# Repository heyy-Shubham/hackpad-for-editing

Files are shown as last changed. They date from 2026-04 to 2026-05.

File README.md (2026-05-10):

h## Hackpad For Editing

## Why I Built This

As a video editor, I was tired of reaching across the keyboard
for shortcuts like Undo, Redo, and Zoom constantly.
I wanted a dedicated device that keeps my hands in the editing
zone — so I built the Hackpad For Editing.

I will make this device using 9 sw_cherry_mx (switch) and encoder and 0.91 oled display
just plug and enhance editing leval build for editors

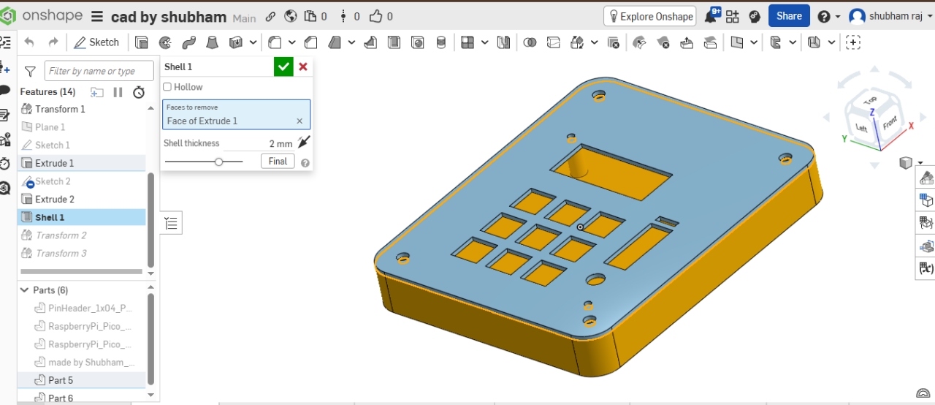
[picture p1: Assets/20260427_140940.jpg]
Hackpad


## What does this do
9 sw_cherry_mx mechanichl switch , Every switch maped editing shortcut 
rotary encoder for layer moveing left And right
Using Like a Standerd Usb Keyboard
Firamware using PlatformIO + keyboard.h in raspbarry pi pico micro controllar

## keyboard shortcuts
| key | Shortcut | Funcation |
|---|---|---|
| SW1 | Tab | Switch between panel |
| SW2 | Win + Swift + S | Screemshot |
| SW3 | Ctrl z | undo |
| SW4 | Ctrl + Swift + z | Redo |
| SW5 | End | Jumpto the end time line |
| SW6 | Alt + 2 | Application specific Shortcut |
| SW7 | Ctrl + B | Split Clip |
| SW8 | Ctrl + = | Zoom in |
| SW9 | Ctrl + - | Zoom Out |
| Encoder Clockwise | Rise Arrow | Time line forward |
| Encoder Anti-Clockwise | Left Arrow | Backward |

## Connectioms Of Respberry To switches
| Component | Pin | 
|---|---|
| SW1 | D2 |
| SW2 | D3 |
| SW3 | D4 |
| SW4 | D5 |
| SW5 | D6 |
| SW6 | D7 |
| SW7 | D8 |
| SW8 | D9 |
| SW9 | D10 |
| Encoder  A | D20 |
| Encoder  B | D21 |

# Component 
1. Switch (sw_cherry_mx)
2. Custom Design PCB
3. Encoder
4. 0.91inch OLED Display
5. Enclosure 

## Firamware Flash in Respberry pi pico
 1. install vs code (https://code.visualstudio.com/)
 2. Add Extension PlatformIO Extension
 3. Select Board And install Firamware

# Fallout Zine Page
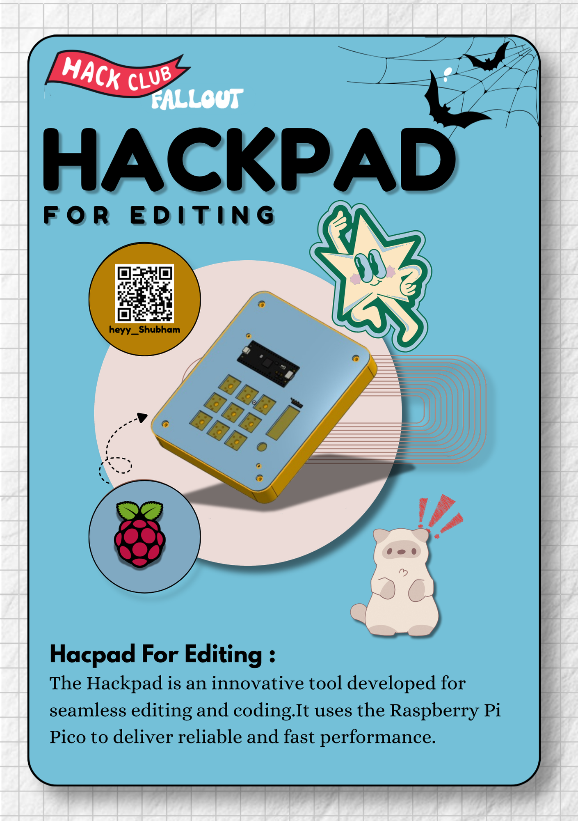
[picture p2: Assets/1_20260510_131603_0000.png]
Poster


## PCB
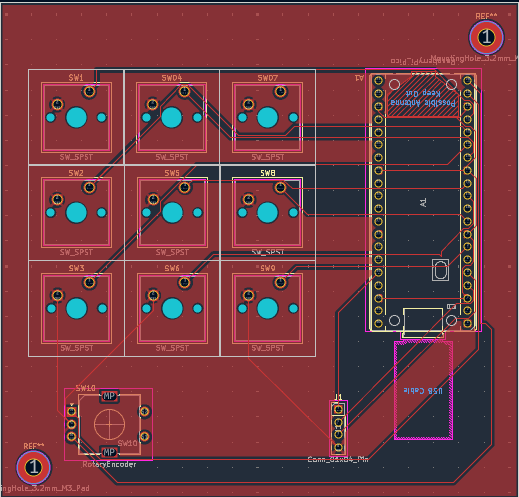
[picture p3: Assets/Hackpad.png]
PCB


# Cad Source File 
OneShap Project Link:
https://cad.onshape.com/documents/5b5dae307a075cbb770b9d40/w/47bce3600617231dbb59e220/e/9a00e2926e7c151da0a35bf5

## CAD
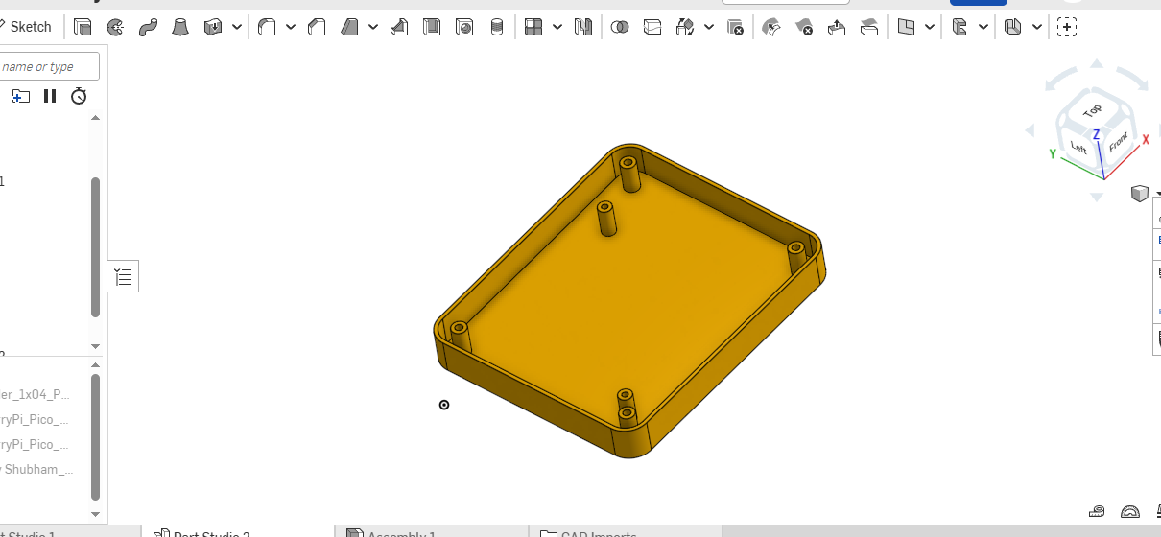
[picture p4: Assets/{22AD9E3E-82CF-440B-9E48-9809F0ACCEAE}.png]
Case


##Author
Shubham Raj - @heyy-Shubham(https://github.com/heyy-shubham)

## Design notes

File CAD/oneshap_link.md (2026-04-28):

# Cad Source File 
OneShap Project Link:
https://cad.onshape.com/documents/5b5dae307a075cbb770b9d40/w/47bce3600617231dbb59e220/e/9a00e2926e7c151da0a35bf5

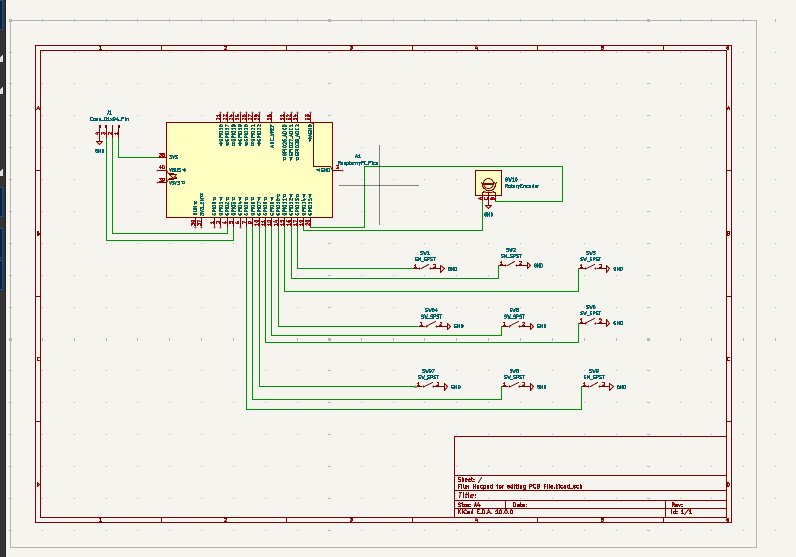
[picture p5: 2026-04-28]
Assets/Screenshot 2026-04-28 001617.png

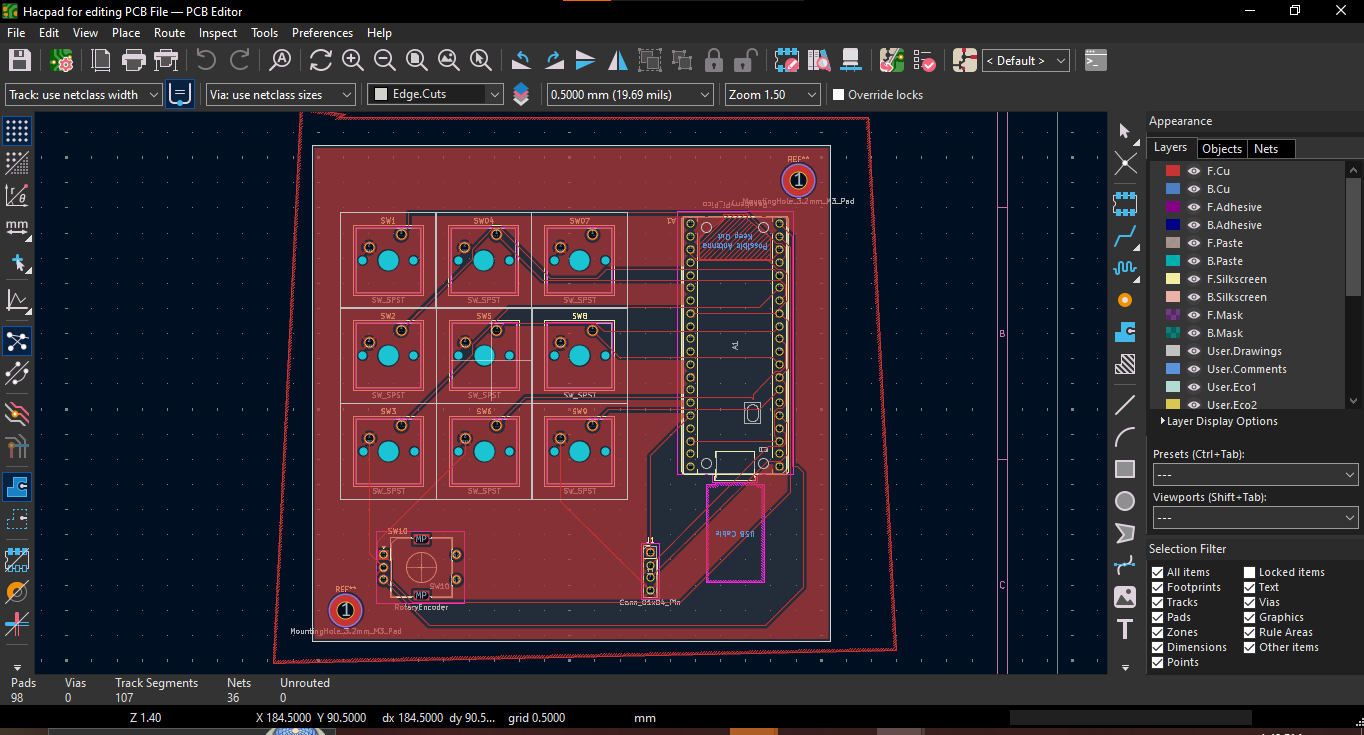
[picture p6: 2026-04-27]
Assets/pcb.jpg

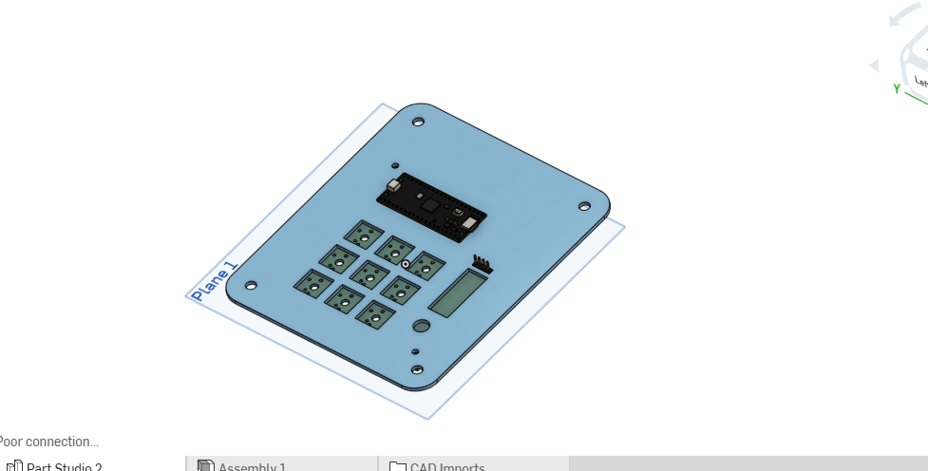
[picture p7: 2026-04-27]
Assets/{4853B936-79CA-4EE4-9DD8-A8C7A89B42EC}.png

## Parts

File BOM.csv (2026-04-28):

Name | Quantity | Price (USD) | Link
Raspberry Pi Pico | 1 | 4.80 | https://robocraze.com/products/raspberry-pi-pico
Cherry MX Switches | 9 | 3.80 | https://meckeys.com/shop/accessories/keyboard-accessories/key-switches/cherry-mx2a-switch/
Rotary Encoder EC11 | 1 | 1.20 | https://amzn.in/d/09X5ElfV
0.91 inch OLED SSD1306 | 1 | 2.60 | https://www.amazon.in/dp/B099X21CM5
3D Printed Case PLA | 1 | 3.00 | https://www.amazon.in
USB Micro Cable | 1 | 1.50 | https://www.amazon.in
PCB Manufacturing JLCPCB | 1 | 5.00 | https://jlcpcb.com

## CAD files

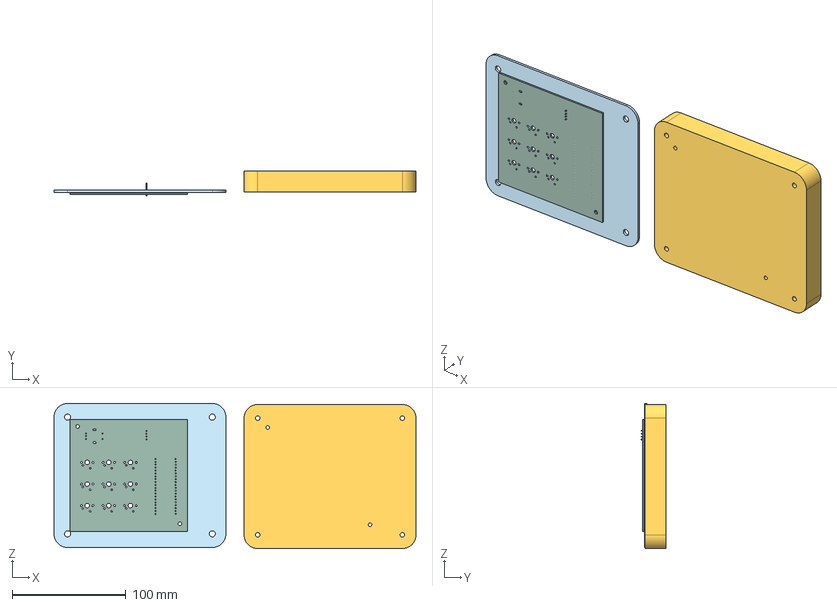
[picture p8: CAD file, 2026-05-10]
CAD/Assembly 1.step
318.3 x 22.2 x 127.5 mm
made by Shubham_PCB
PinHeader_1x04_P2.54mm_Vertical

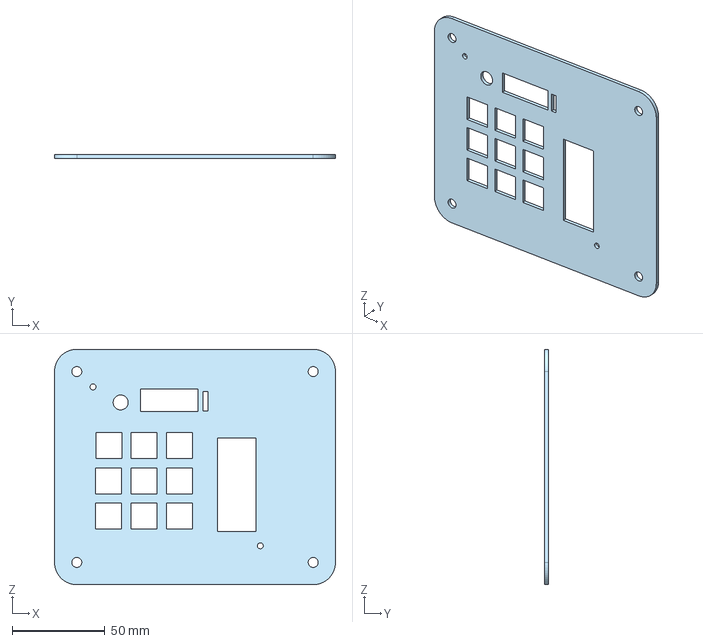
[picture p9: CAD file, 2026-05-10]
CAD/Part Studio 2 - Part 6.step
151.2 x 2.00 x 126.6 mm

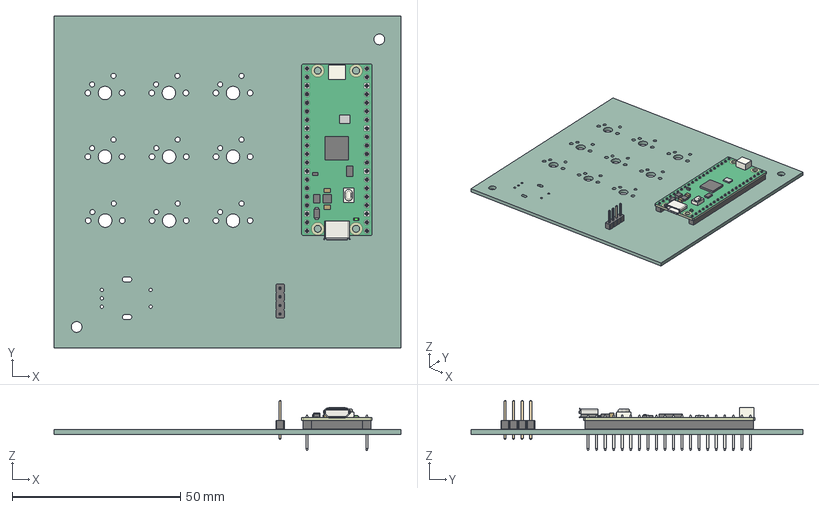
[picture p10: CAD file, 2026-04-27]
PCB/.step
103.2 x 98.6 x 14.9 mm
PinHeader_1x04_P2.54mm_Vertical
RaspberryPi_Pico_H_Module_KiCad
RaspberryPi_Pico_Header_DIP-40_H2.54mm_KiCad
made by Shubham_PCB

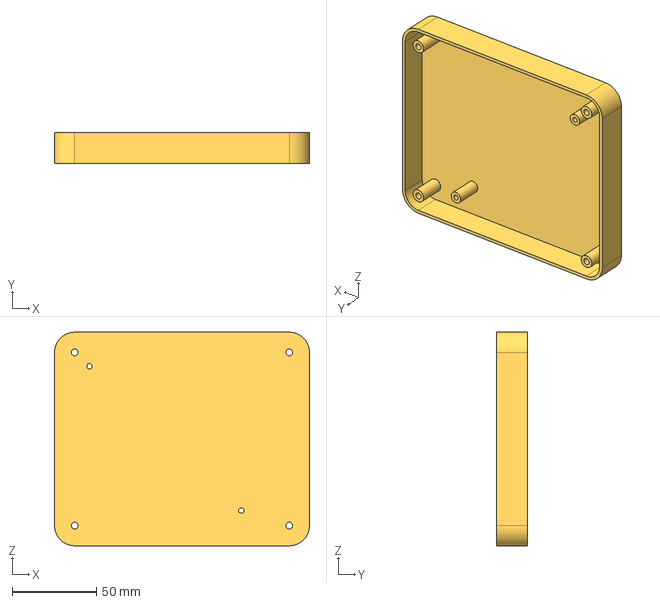
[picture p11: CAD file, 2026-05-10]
CAD/Part Studio 2 - Part 5 (1).step
151.2 x 18.5 x 126.6 mm

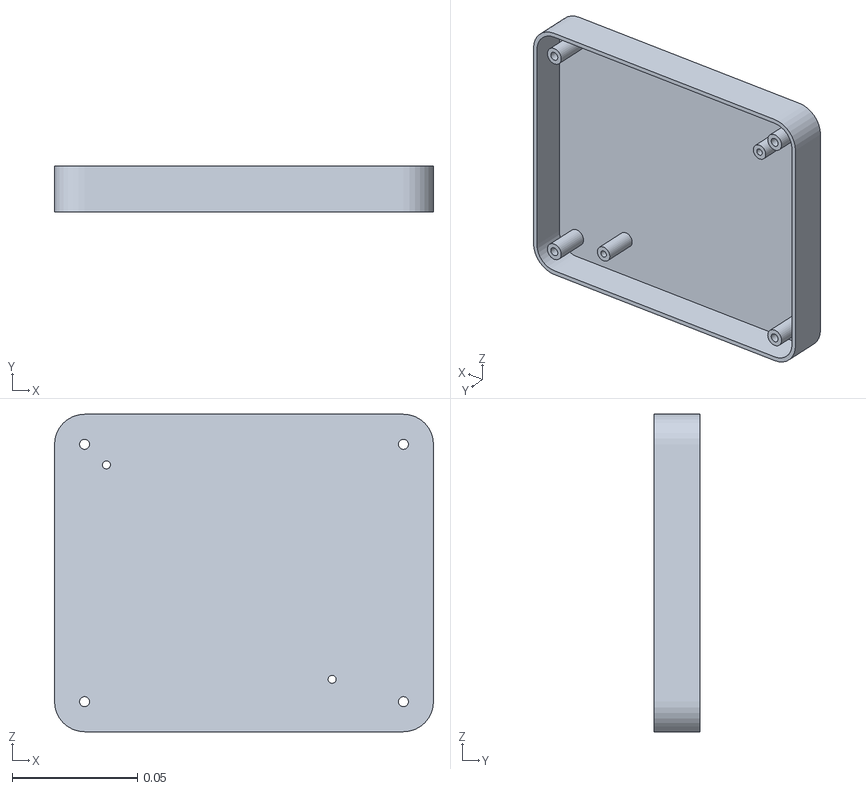
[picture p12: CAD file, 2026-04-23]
CAD/Body.stl
0.151 x 0.0185 x 0.127

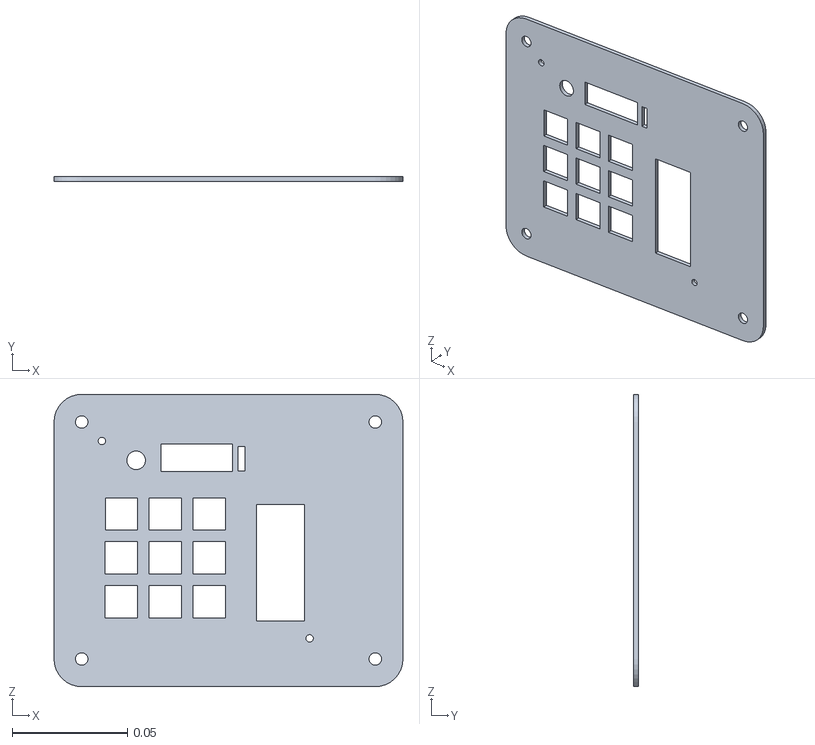
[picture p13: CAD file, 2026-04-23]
CAD/Top.stl
0.151 x 0.002 x 0.127

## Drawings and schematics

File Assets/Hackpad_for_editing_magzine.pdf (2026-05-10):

## HACKPAD F O R E D I T I N G

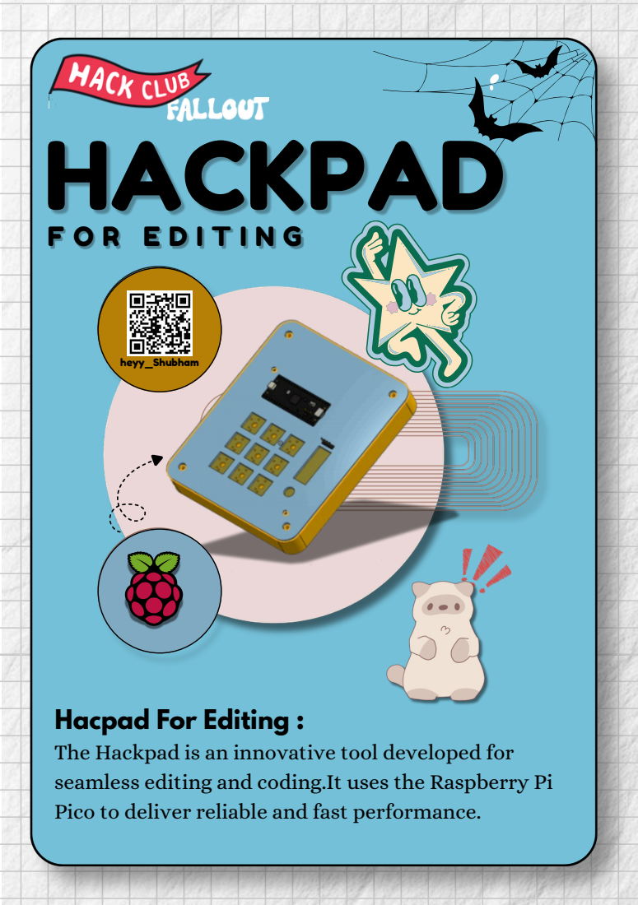
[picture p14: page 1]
heyy_Shubham

Hacpad For Editing :
The Hackpad is an innovative tool developed for
seamless editing and coding.It uses the Raspberry Pi
Pico to deliver reliable and fast performance.

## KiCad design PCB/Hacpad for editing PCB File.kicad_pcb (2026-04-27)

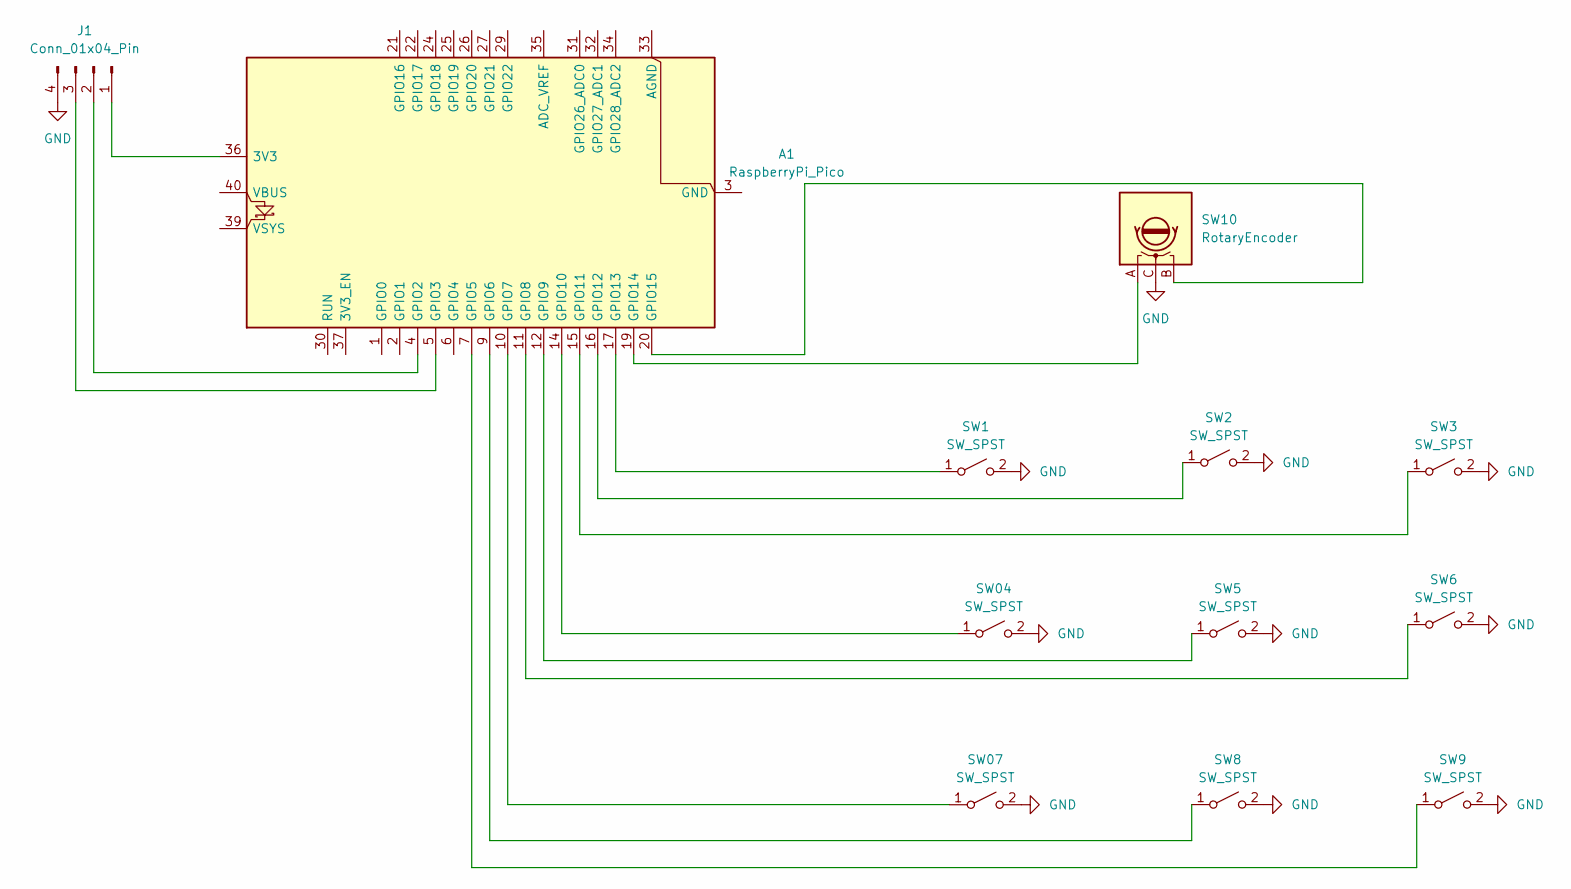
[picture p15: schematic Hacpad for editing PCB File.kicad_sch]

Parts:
A1: RaspberryPi_Pico; RaspberryPi_Pico_Common_Unspecified
J1: Conn_01x04_Pin; PinHeader_1x04_P2.54mm_Vertical
SW1, SW2, SW3, SW04, SW5, SW6, SW07, SW8, SW9: SW_SPST; SW_Cherry_MX_1.00u_PCB
SW10: RotaryEncoder; RotaryEncoder_Alps_EC11E-Switch_Vertical_H20mm

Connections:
GND: J1.4, SW1.2 (B), SW2.2 (B), SW3.2 (B), SW04.2 (B), SW5.2 (B), SW6.2 (B), SW07.2 (B_2), SW8.2 (B), SW9.2 (B), SW10.C
unnamed: A1.36 (3V3), J1.1
unnamed: A1.3 (GND), A1.8 (GND), A1.13 (GND), A1.18 (GND), A1.23 (GND), A1.28 (GND), A1.38 (GND)
unnamed: A1.4 (GPIO2), J1.2
unnamed: A1.5 (GPIO3), J1.3
unnamed: A1.7 (GPIO5), SW9.1 (A)
unnamed: A1.9 (GPIO6), SW8.1 (A)
unnamed: A1.11 (GPIO8), SW6.1 (A)
unnamed: A1.12 (GPIO9), SW5.1 (A)
unnamed: A1.14 (GPIO10), SW04.1 (A)
unnamed: A1.15 (GPIO11), SW3.1 (A)
unnamed: A1.16 (GPIO12), SW2.1 (A)
unnamed: A1.17 (GPIO13), SW1.1 (A)
unnamed: A1.19 (GPIO14), SW10.A
unnamed: A1.20 (GPIO15), SW10.B

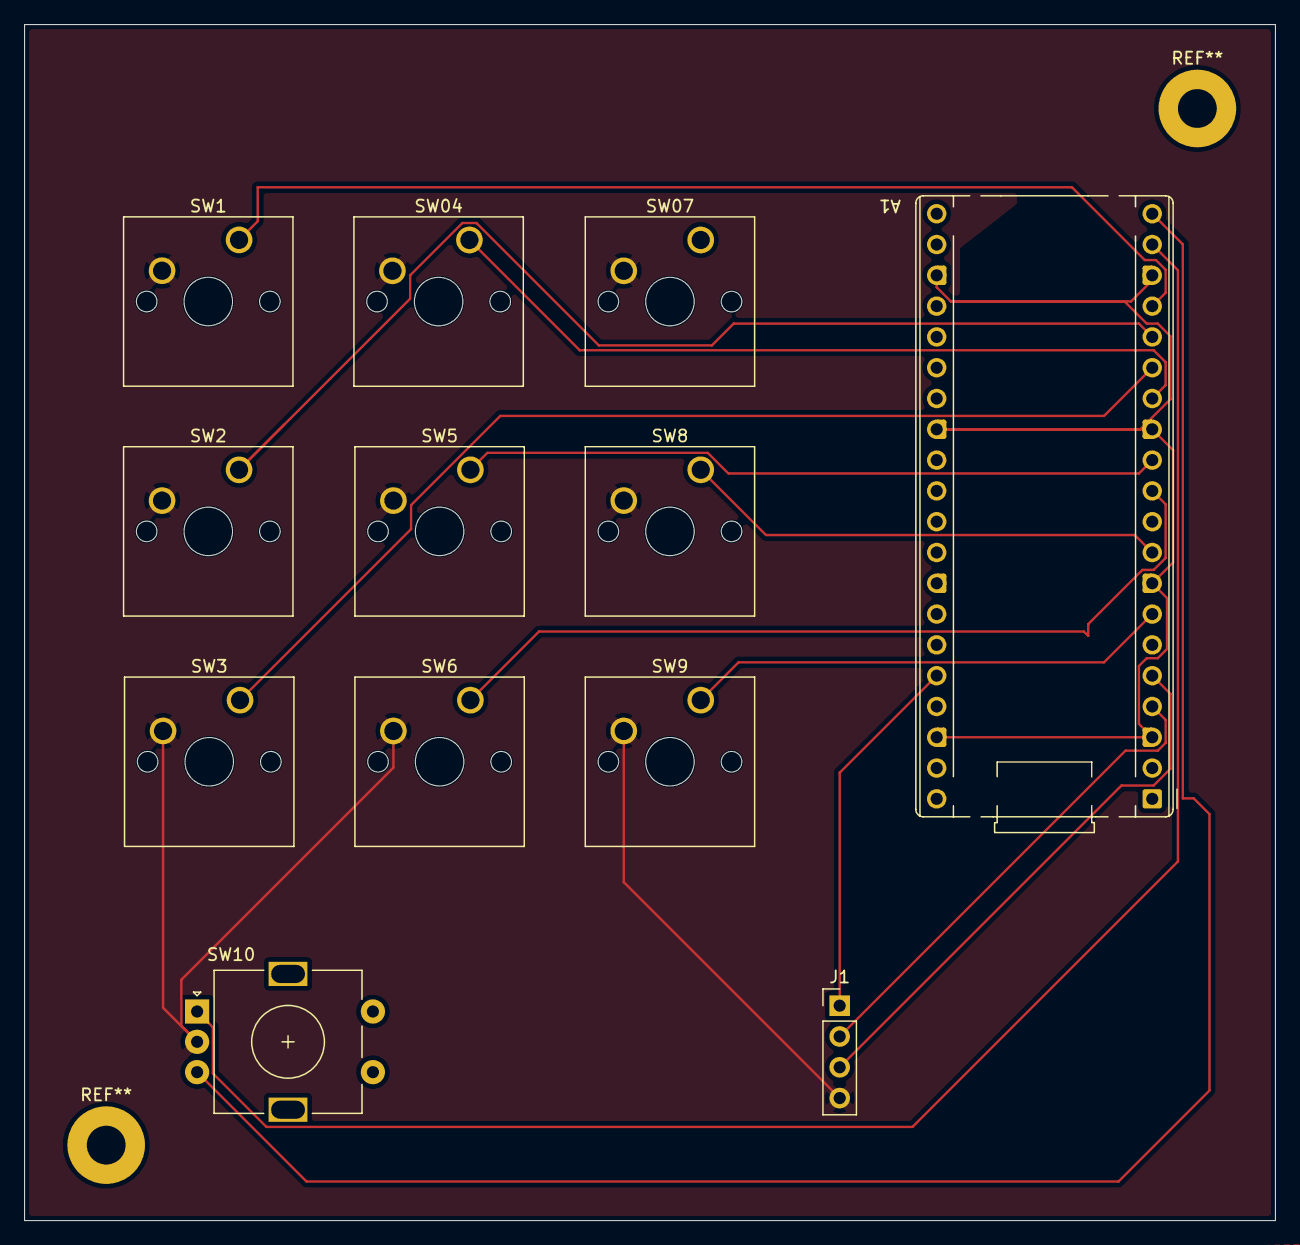
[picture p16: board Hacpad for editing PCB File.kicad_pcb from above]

Board: 2 copper layers, 103.2 x 98.6 mm, 12 parts (0 on the bottom side), 15 nets.

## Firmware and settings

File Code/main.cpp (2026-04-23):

#include <Arduino.h>
#include <Keyboard.h>

#define SW1  2
#define SW2  3
#define SW3  4
#define SW4  5
#define SW5  6
#define SW6  7
#define SW7  8
#define SW8  9
#define SW9  10
#define ENC_A 20
#define ENC_B 21

bool lastA = HIGH;
const int buttons[] = {SW1,SW2,SW3,SW4,SW5,SW6,SW7,SW8,SW9};
const int NUM_BUTTONS = 9;
bool lastState[9];
unsigned long lastPress[9];
#define DEBOUNCE 50

void pressKey(int sw) {
  switch (sw) {
    case 0: Keyboard.press(KEY_TAB); Keyboard.releaseAll(); break;
    case 1: Keyboard.press(KEY_LEFT_GUI); Keyboard.press(KEY_LEFT_SHIFT); Keyboard.press('s'); Keyboard.releaseAll(); break;
    case 2: Keyboard.press(KEY_LEFT_CTRL); Keyboard.press('z'); Keyboard.releaseAll(); break;
    case 3: Keyboard.press(KEY_LEFT_CTRL); Keyboard.press(KEY_LEFT_SHIFT); Keyboard.press('z'); Keyboard.releaseAll(); break;
    case 4: Keyboard.press(KEY_END); Keyboard.releaseAll(); break;
    case 5: Keyboard.press(KEY_LEFT_ALT); Keyboard.press('2'); Keyboard.releaseAll(); break;
    case 6: Keyboard.press(KEY_LEFT_CTRL); Keyboard.press('b'); Keyboard.releaseAll(); break;
    case 7: Keyboard.press(KEY_LEFT_CTRL); Keyboard.press('='); Keyboard.releaseAll(); break;
    case 8: Keyboard.press(KEY_LEFT_CTRL); Keyboard.press('-'); Keyboard.releaseAll(); break;
  }
}

void setup() {
  for (int i = 0; i < NUM_BUTTONS; i++) {
    pinMode(buttons[i], INPUT_PULLUP);
    lastState[i] = HIGH;
    lastPress[i] = 0;
  }
  pinMode(ENC_A, INPUT_PULLUP);
  pinMode(ENC_B, INPUT_PULLUP);
  lastA = digitalRead(ENC_A);
  Keyboard.begin();
}

void loop() {
  for (int i = 0; i < NUM_BUTTONS; i++) {
    bool state = digitalRead(buttons[i]);
    if (state == LOW && lastState[i] == HIGH) {
      if (millis() - lastPress[i] > DEBOUNCE) {
        pressKey(i);
        lastPress[i] = millis();
      }
    }
    lastState[i] = state;
  }
  bool currA = digitalRead(ENC_A);
  bool currB = digitalRead(ENC_B);
  if (currA != lastA) {
    if (currB != currA) { Keyboard.press(KEY_RIGHT_ARROW); Keyboard.releaseAll(); }
    else { Keyboard.press(KEY_LEFT_ARROW); Keyboard.releaseAll(); }
    lastA = currA;
  }
}

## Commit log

2026-04-23 Add Arduino keyboard control for multiple buttons code
    A PlatformIO-based project for efficient code editing and embedded development using VS Code.
2026-04-23 CAD
    This is a encloser cad model for hackpad editor
    [Part Studio 2 - Part 6.stl]
2026-04-23 schematic of pcb
    [made by Shubham.kicad_sch]
2026-04-26 schematic
    schematic for PCB
2026-04-27 Rename Part Studio 2 - Part 5 (1).stl to CAD/Part Studio 2 - Part 5 (1).stl
    [Part Studio 2 - Part 5 (1).stl]
2026-04-27 Rename Part Studio 2 - Part 6.stl to CAD/Part Studio 2 - Part 6.stl
    [Part Studio 2 - Part 6.stl]
2026-04-27 Rename made by Shubham.kicad_sch to PCB/made by Shubham.kicad_sch
    [made by Shubham.kicad_sch]
2026-04-27 PCB of Hackpad for editing
    [.step, Hacpad for editing PCB File.kicad_pcb, Hacpad for editing PCB File.kicad_sch]
2026-04-27 Cad of our encloser
2026-04-27 Top Case of Encloser
2026-04-27 PCB Image
2026-04-27 Rename Screenshot 2026-04-27 134920.png to pcb.jpg
2026-04-28 schematics of pcb
2026-04-28 Rename Part Studio 2 - Part 5 (1).stl to Body.stl
    [Body.stl]
2026-04-28 Rename Part Studio 2 - Part 6.stl to Top.stl
    [Top.stl]
2026-05-10 Add OneShap project link to README
    Added OneShap project link for CAD source file.
2026-05-10 Encoloser Bottem STEP File
    [Part Studio 2 - Part 5 (1).step]
2026-05-10 Encloser Top STEP file
    [Part Studio 2 - Part 6.step]
